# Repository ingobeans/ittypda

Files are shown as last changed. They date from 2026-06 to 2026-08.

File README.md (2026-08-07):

# ittyPDA
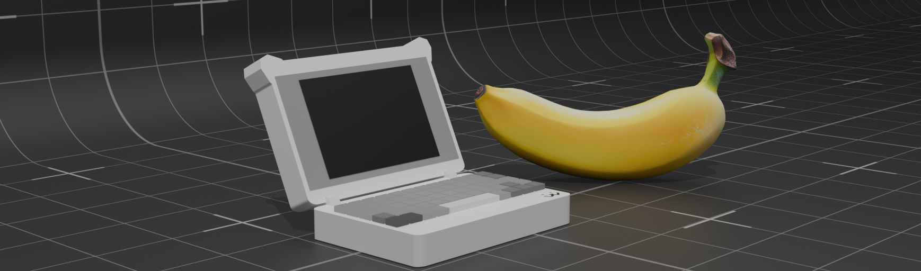
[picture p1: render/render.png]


hi! this is my little thing im working on.

ittyPDA is an itty-bitty PDA/cyberdeck thingy. its smaller than a nintendo ds but has a real keyboard and a full color IPS LCD display, powered by an STM32 microcontroller.

it's mainly intended for note-taking/writing, playing silly little videogames, and just being a very hackable little computer.

this repo contains both the hardware designs, under the `ittypda/` subdirectory, as well as the operating system under `ittyOS/`. 3D case files are under `case/`.

## specs & parts

* microprocessor: [STM32F411RET6](https://www.st.com/en/microcontrollers-microprocessors/stm32f411re.html)
    * Up to 100 MHz
    * 512 Kb flash
    * 128 Kb RAM
* display: [3.5" IPS display (no touch version)](https://www.lcdwiki.com/3.5inch_IPS_SPI_Module_ST7796)
* storage: SD card slot included on display
* charging/data transfer possible over USB-C
* battery: 2200mAh LiPo - [this is the one I use, but really any battery with a similar size and connector will work](https://www.amazon.se/-/en/gp/product/B0D7VT93JX?smid=A2YUU8D7JQVZCY&th=1)
* on-board charging circuitry powered by a [BQ24040DSQR](https://www.ti.com/product/BQ24040)
    * also battery level sensing

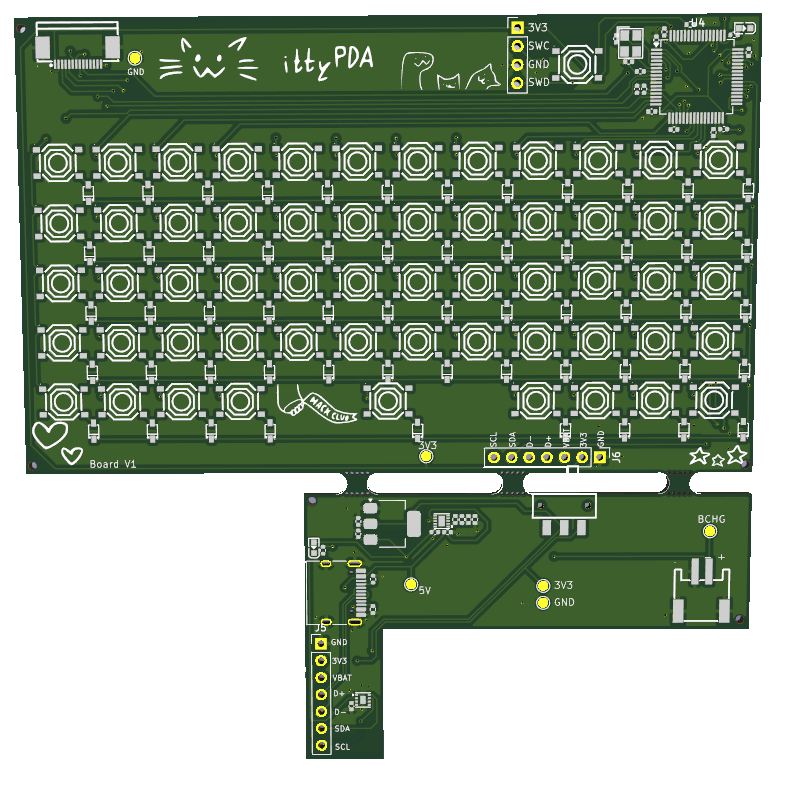
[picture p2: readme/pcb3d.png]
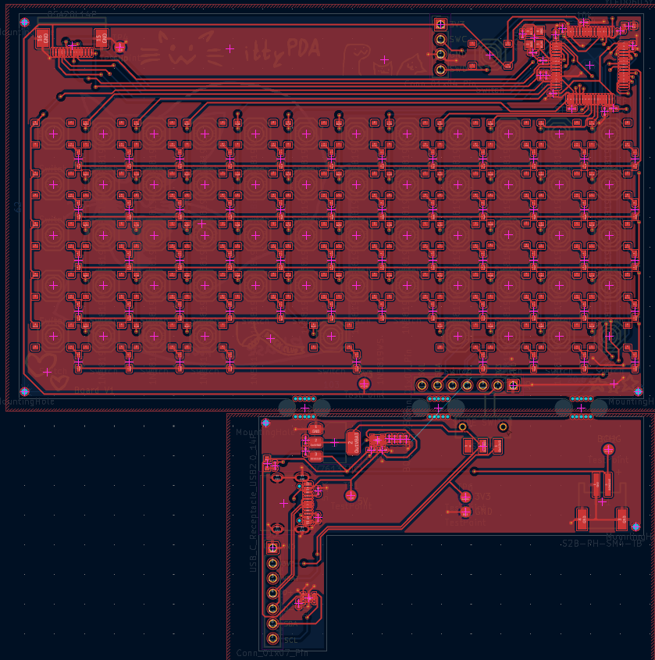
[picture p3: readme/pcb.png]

## download symbols/footprints

to open the kicad project, youll need to download some footprints. my parts are sourced from JLCPCB's parts / LCSC, and you can use [`easyeda2kicad`](https://github.com/uPesy/easyeda2kicad.py) to download LCSC parts to kicad.

the command you need to run is: 

```bash
easyeda2kicad --full --lcsc_id C318884 C191023 C22435642 C13738 C81080 C49023767 C19273152 C165948 C295747 C20416998 C2682616
```

which will download footprints/symbols/3d models for the switches, diodes, etc.

## project status (important !!)

project is in a very early WIP state currently! the PCB is the only truly *finished* part so far.

the case is just a minimum-viable-product for now, and the firmware mostly acts as a proof-of-concept regarding graphics streaming and input handling from the keyboard matrix.

thus the project is mostly about the creation of the PCB, with the case and firmware mostly just acting as beta features used to test the PCB itself.

these features will be developed in the coming months though, and when i have guaranteed that the core PCB does work! this is a project i intend to gradually work on for a long time !

## schematic / PCB

the schematic and PCB are designed in KiCad, files for which are found in `ittypda/`.

the PCB is split in two seperate parts. this is done to achieve a budget 4-layer board, and to get around the fact that JLCPCB's economy PCBA service cant assemble parts on the bottomside of the board.

the mainboard houses the microcontroller, the keypad, and display connector.

the secondary board houses the usb-c port, battery charging ic, voltage regulator, etc.

the two boards mount together like a PCB-sandwich and connect through 7 soldered pads.

showcase how the two boards are mounted:

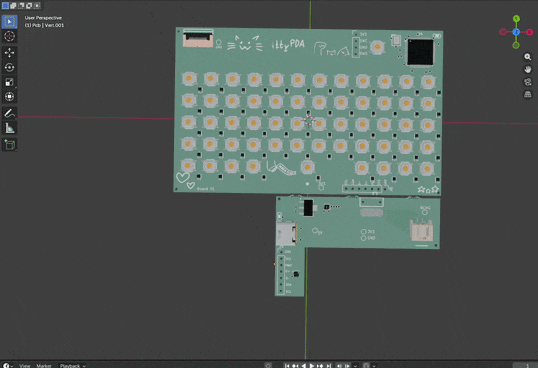
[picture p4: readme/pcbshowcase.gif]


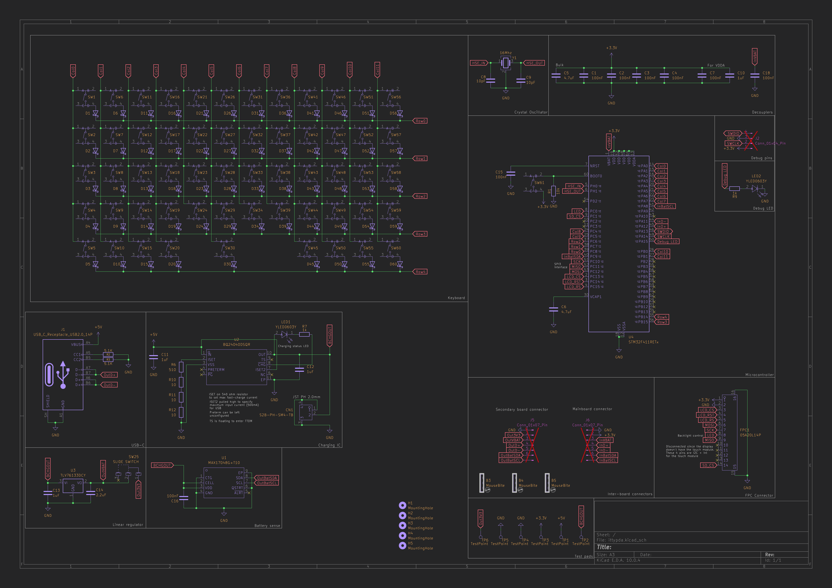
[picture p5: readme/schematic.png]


## firmware - ittyOS

ittyOS is currently in an early proof of concept state, but will have many different apps later on.

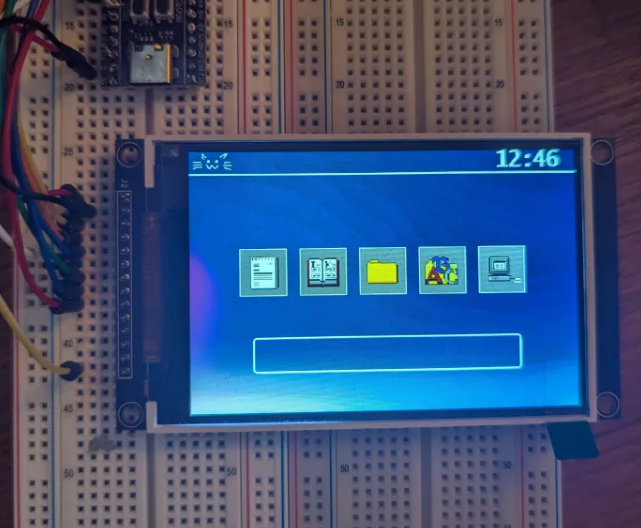
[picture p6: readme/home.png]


implemented:
* display drivers
* reading from microSD card
* streaming image data from microSD to screen
* input from keyboard
* program switching
* basic home screen
* basic notes app

todo:
* improve text input
* usb file transfer
* more apps!
    * wordle
    * journal
* different themes?

### compile ittyOS

the `../firmware` folder contains the low level hardware setup for different boards that can run ittyOS, while `ittyOS/` contains the shared code and the actual system, which is then linked to from the firmware.

you'll need to generate the firmware code from the STM32 project file, since the low-level drivers for these boards are very large and therefore gitignored. you'll need STM32CubeMX. then just open the project file for the firmware you want to build, and hit generate code. 

you'll also have to tell your LSP which CMakeLists you're using.

then, to build, navigate to the firmware you want to build's directory.

1. `cmake --preset Debug` (you only have to run this once)
2. `cmake --build --preset Debug`
3. `STM32_Programmer_CLI -c port=swd -w build/Debug/<DEVBOARD OR ITTYPDA HERE>.elf -v -rst`

## case

the case files are located under `case/`.

the case is designed in,.. blender. its mostly a MVP for a case, and when i get the phyiscal PCB, this and the firmware will be the major focus for the project moving forwards.

most parts are designed to friction-fit, though i wont know how well this works in practice, but will find out soon !

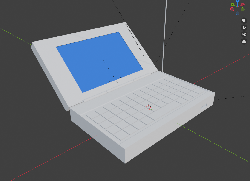
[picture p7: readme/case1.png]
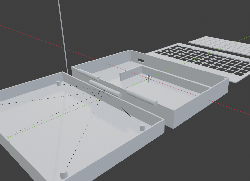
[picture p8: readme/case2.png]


## BOMs

### Final bom (bom.csv)

|Name |Cost ($) |Source |
|---|---|---|
|PCB |13.43 |JLCPCB |
|PCB Assembly Fees |48.21 |JLCPCB |
|PCB Assembly Components |20.55 |JLCPCB |
|PCB Shipping |24.07 | DHL Express |
|Customs & taxes | 26.56 | |
|Total |132.77 | |

### Parts bom (parts-bom.csv)

|Part Name |Description |Link |Quantity |Total Price ($) |
|---|---|---|---|---|
|CL05B104KO5NNNC |100nF 0402 Ceramic Capacitors |https://jlcpcb.com/partdetail/1877-CL05B104KO5NNNC/C1525 |16 |0.0864 |
|CL05A475MP5NRNC |10V 0402 Ceramic Capacitors |https://jlcpcb.com/partdetail/24469-CL05A475MP5NRNC/C23733 |4 |0.0828 |
|CL05C100JB5NNNC |10pF 0402 Ceramic Capacitors |https://jlcpcb.com/partdetail/33914-CL05C100JB5NNNC/C32949 |4 |0.0212 |
|CL05A105KA5NQNC |1uF 0402 Ceramic Capacitors |https://jlcpcb.com/partdetail/53938-CL05A105KA5NQNC/C52923 |8 |0.1272 |
|CL05A225MQ5NSNC |2.2uF 0402 Ceramic Capacitors |https://jlcpcb.com/partdetail/13164-CL05A225MQ5NSNC/C12530 |2 |0.0128 |
|S2B-PH-SM4-TB(LF)(SN) |PH JST Connector 2mm |https://jlcpcb.com/partdetail/JST-S2B_PH_SM4_TB_LF_SN/C295747 |2 |0.427 |
|1N5819WS |Schottky Diodes |https://jlcpcb.com/partdetail/GuangdongHottech-1N5819WS/C191023 |114 |1.5504 |
|05A20L14P |FPC Connector |https://jlcpcb.com/partdetail/HanElectricity-05A20L14P/C22435642 |2 |0.1404 |
|TYPE-C-31-M-12 |USB-C Connectors |https://jlcpcb.com/partdetail/Korean_HropartsElec-TYPE_C_31_M12/C165948 |2 |0.3686 |
|YLED0603Y |Yellow 0603 LED |https://jlcpcb.com/partdetail/YONGYUTAI-YLED0603Y/C19273152 |20 |0.13 |
|0402WGF1002TCE |10k ohm 0402 Resistor |https://jlcpcb.com/partdetail/26487-0402WGF1002TCE/C25744 |2 |0.023 |
|0402WGF5101TCE |5.1k ohm 0402 Resistor |https://jlcpcb.com/partdetail/26648-0402WGF5101TCE/C25905 |4 |0.0268 |
|0402WGF5100TCE |510 ohm 0402 Resistor |https://jlcpcb.com/partdetail/25866-0402WGF5100TCE/C25123 |2 |0.0122 |
|0402WGF1001TCE |1k ohm 0402 Resistor |https://jlcpcb.com/partdetail/12256-0402WGF1001TCE/C11702 |4 |0.0392 |
|0402WGF100JTCE |10 ohm 0402 Resistor |https://jlcpcb.com/partdetail/25820-0402WGF100JTCE/C25077 |6 |0.0342 |
|TS-1187A-B-A-B |Tactile Switches |https://jlcpcb.com/partdetail/XKBConnection-TS_1187A_B_AB/C318884 |116 |2.3664 |
|MST-12D18G4 SPDT | Slide Switch |https://jlcpcb.com/partdetail/C49023767 |2 |0.1654 |
|MAX17048G+T10 |Battery Sense IC MAX17048GT10 |https://jlcpcb.com/partdetail/2777647-MAX17048GT10/C2682616 |2 |4.3212 |
|BQ24040DSQR |Lithium Battery Charge IC BQ24040DSQR |https://jlcpcb.com/partdetail/TexasInstruments-BQ24040DSQR/C81080 |5 |2.243 |
|TLV76133DCYR |3.3V Fixed Voltage Regulators - Linear|https://jlcpcb.com/partdetail/TexasInstruments-TLV76133DCYR/C7527500 |2 |0.438 |
|STM32F411RET6 |Microcontroller |https://jlcpcb.com/partdetail/STMicroelectronics-STM32F411RET6/C94355 |2 |7.7452 |
|X322516MLB4SI |16MHz 9pF Crystal Oscillator |https://jlcpcb.com/partdetail/YXC_CrystalOscillators-X322516MLB4SI/C13738 |2 |0.1856 |

<hr>

<sup>no ai usage</sup>

<sup>made with <3</sup>

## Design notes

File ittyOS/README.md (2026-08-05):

# ittyOS

hiya! this folder contains the code for the shared operating system. 

the `../firmware` folder contains the low level hardware setup for different boards that can run ittyOS, that all link to this directory and act as bootloaders.

the `FS/` directory contains the files i have on my microSD card which contains some images used by ittyOS. how this works will be changed later in development with automatic SD card formatting tools, but for now you can simply format your SD card for FAT and upload this filetree.

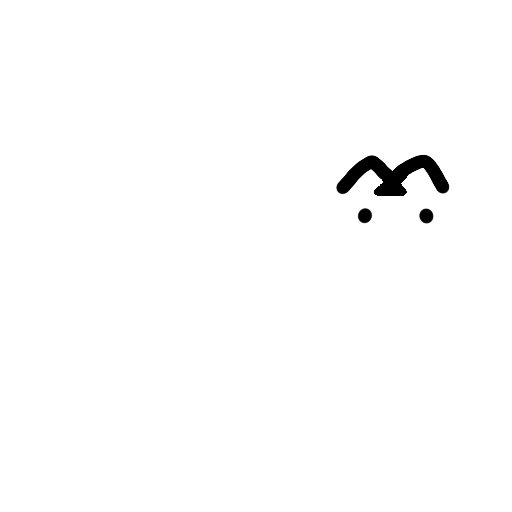
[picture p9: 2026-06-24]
render/decal.png

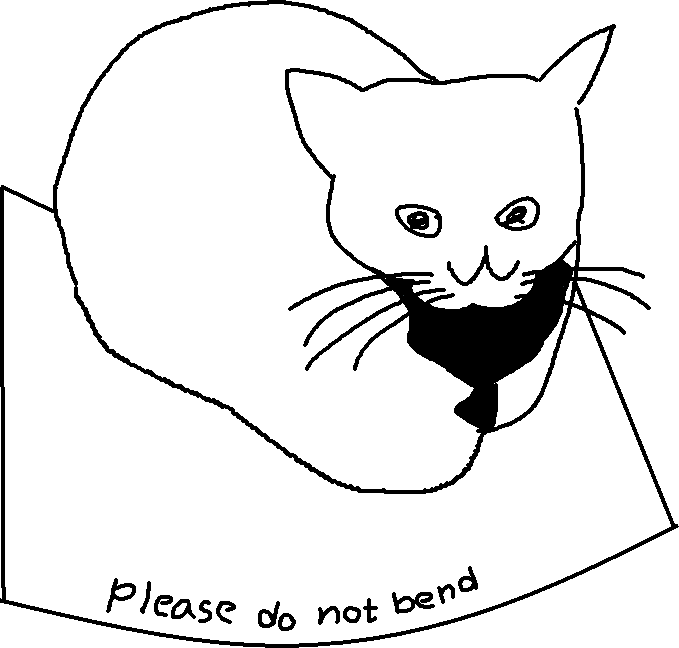
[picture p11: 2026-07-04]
ittypda/silkscreen/bend.png

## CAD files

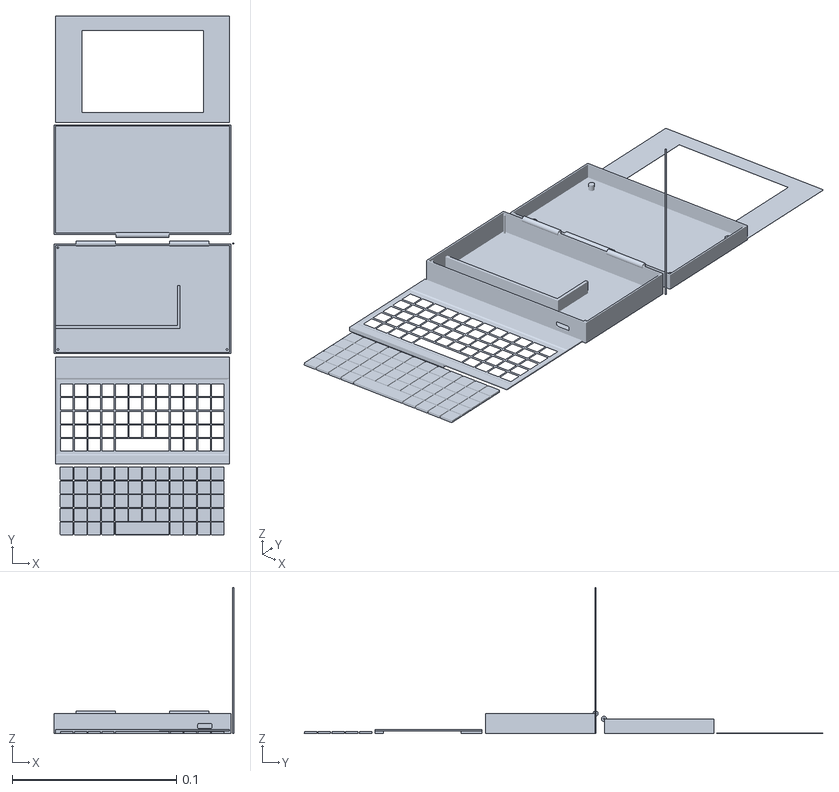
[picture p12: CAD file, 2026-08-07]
case/case-printable.stl
0.109 x 0.316 x 0.0891

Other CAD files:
case/case-printable.blend
mockup.blend

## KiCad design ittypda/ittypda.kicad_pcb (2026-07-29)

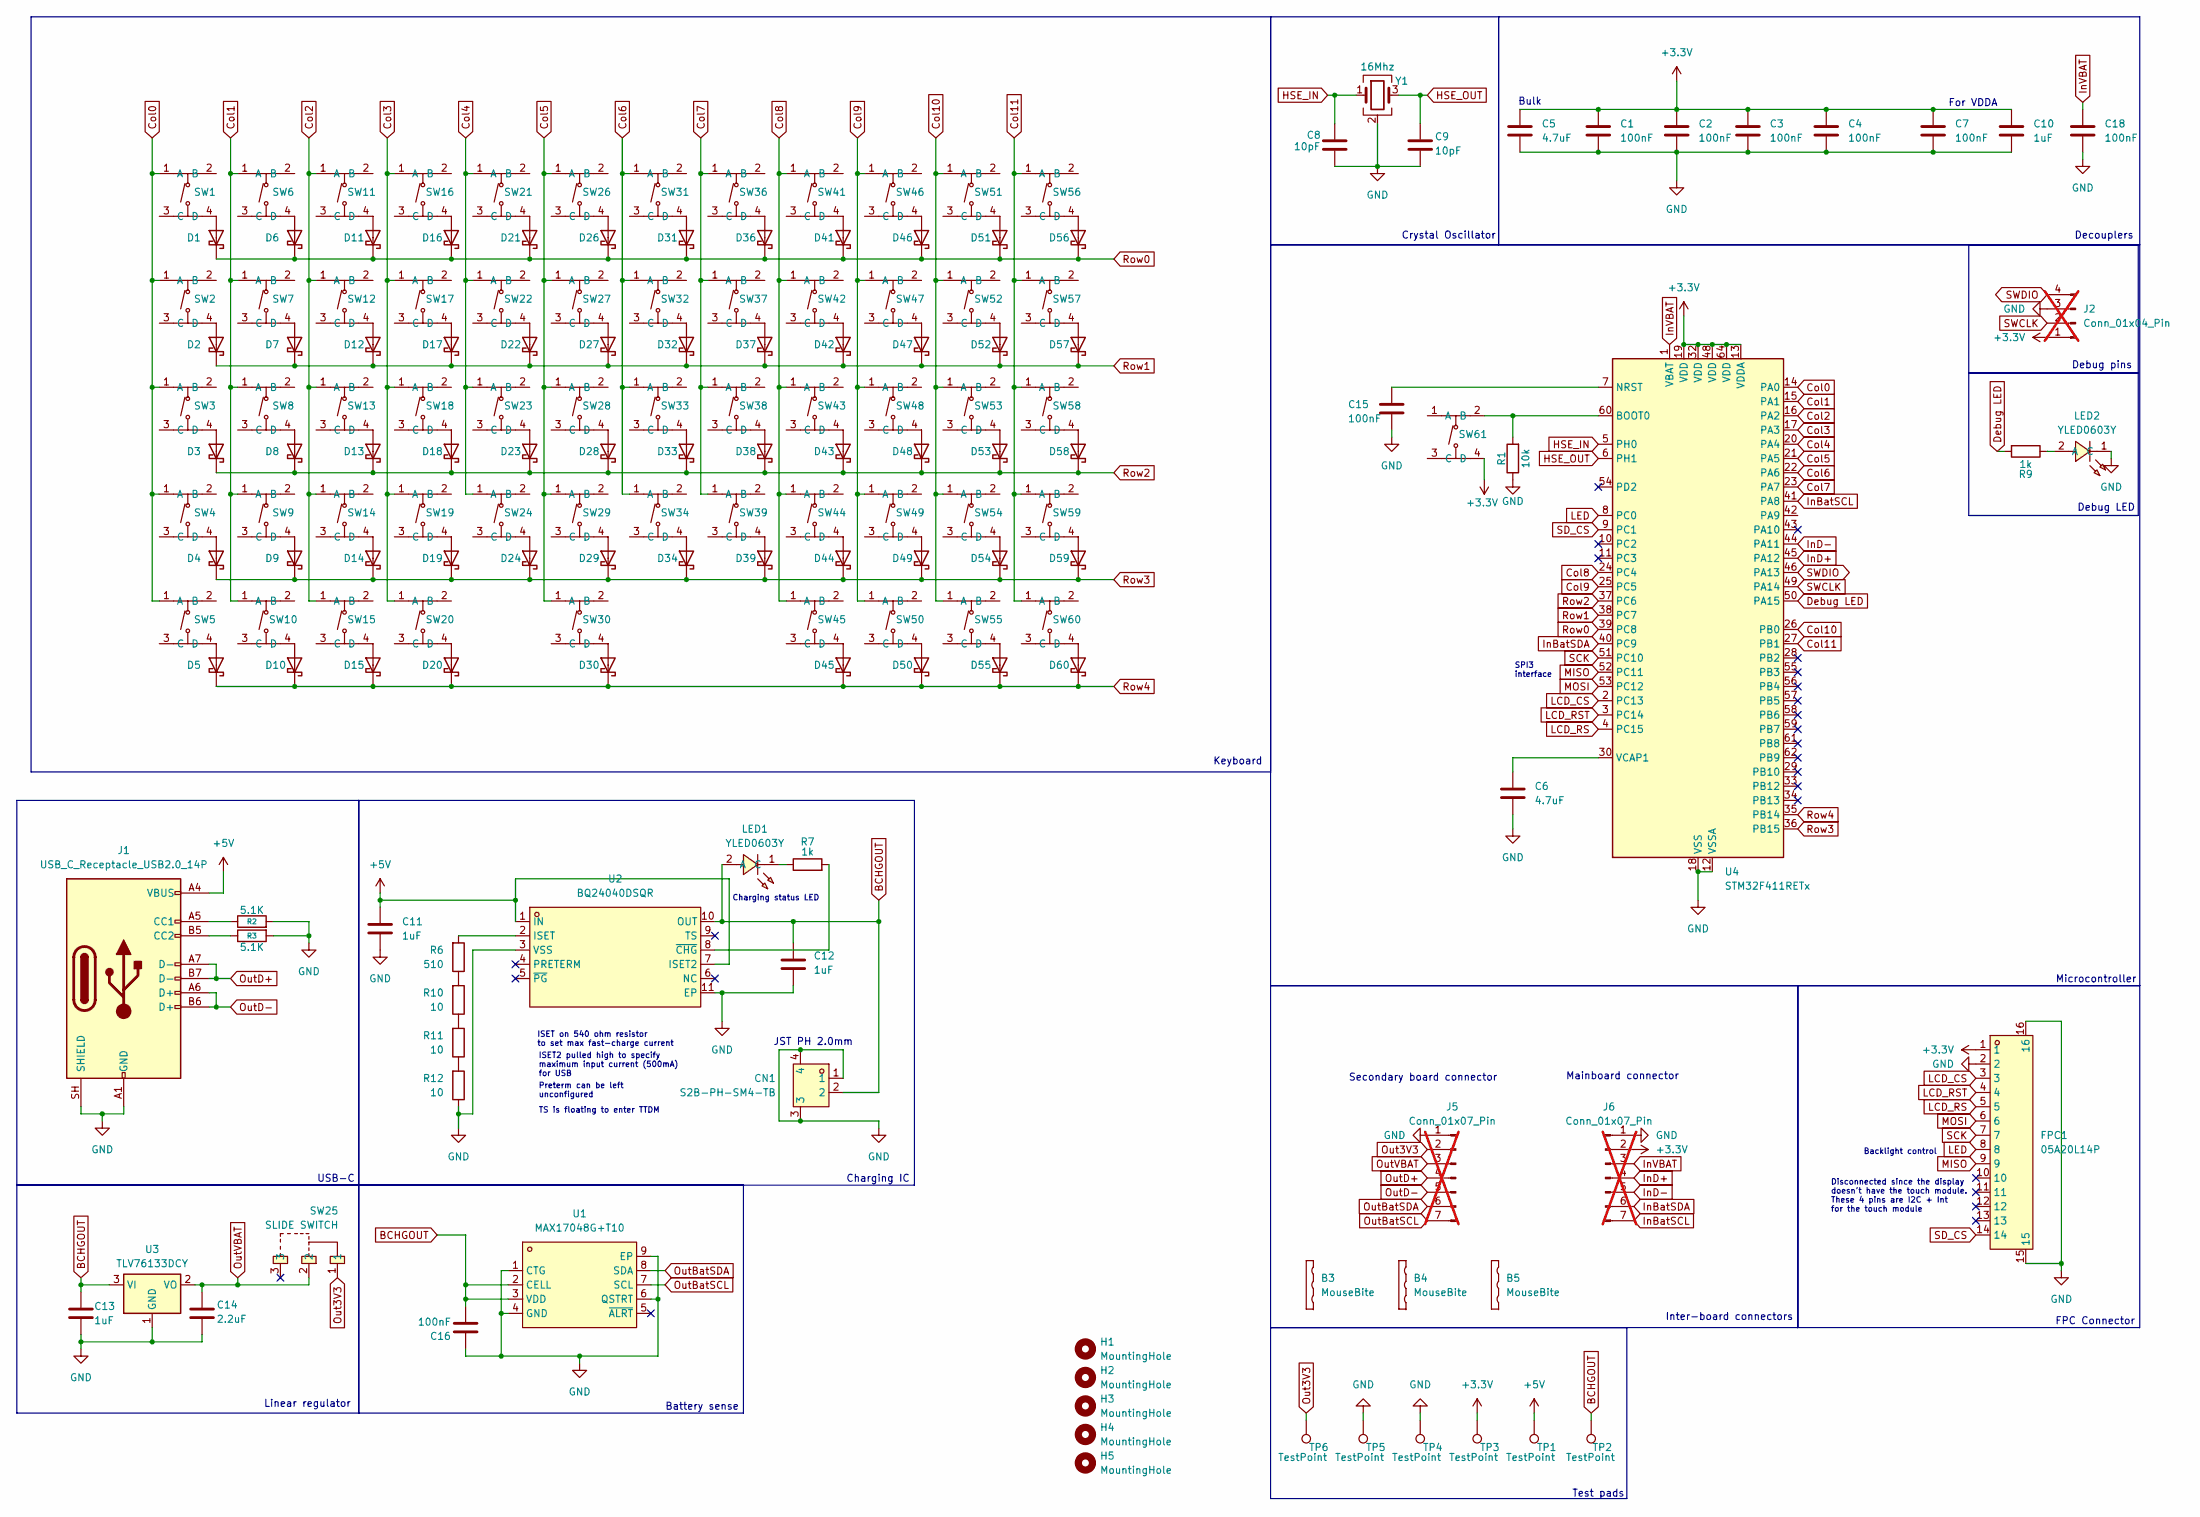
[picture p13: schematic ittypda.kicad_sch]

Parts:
B3, B4, B5: MouseBite; mouse-bite-3mm-slot
C1, C2, C3, C4, C7, C15, C16, C18: 100nF; C_0402_1005Metric
C5, C6: 4.7uF; C_0402_1005Metric
C8, C9: 10pF; C_0402_1005Metric
C10, C11, C12, C13: 1uF; C_0402_1005Metric
C14: 2.2uF; C_0402_1005Metric
CN1: S2B-PH-SM4-TB; CONN-SMD_P2.00_S2B-PH-SM4-TB-LF-SN; MPN S2B-PH-SM4-TB(LF)(SN); LCSC Part C295747
D1, D2, D3, D4, D5, D6, D7, D8, D9, D10, D11, D12, D13, D14, D15, D16, D17, D18, D19, D20, D21, D22, D23, D24, D26, D27, D28, D29, D30, D31, D32, D33, D34, D36, D37, D38, D39, D41, D42, D43, D44, D45, D46, D47, D48, D49, D50, D51, D52, D53, D54, D55, D56, D57, D58, D59, D60: 1N5819WS; SOD-323_L1.8-W1.3-LS2.5-RD; Forward Voltage (Vf@If) 600mV@1A; Reverse Voltage (Vr) 40V; Part 1N5819WS; LCSC C191023
FPC1: 05A20L14P; CONN-SMD_05A20L14P; MPN 05A20L14P; LCSC Part C22435642
H1, H2, H3, H4, H5: MountingHole; ToolingHole_1.152mm
J1: USB_C_Receptacle_USB2.0_14P; USB_C_Receptacle_HRO_TYPE-C-31-M-12; LCSC Part C165948
J2: Conn_01x04_Pin; PinHeader_1x04_P2.54mm_Vertical; not fitted
J5, J6: Conn_01x07_Pin; PinHeader_1x07_P2.54mm_Vertical; not fitted
LED1, LED2: YLED0603Y; LED0603-RD-1; MPN YLED0603Y; LCSC Part C19273152
R1: 10k; R_0402_1005Metric
R2, R3: 5.1K; R_0402_1005Metric
R6: 510; R_0402_1005Metric
R7, R9: 1k; R_0402_1005Metric
R10, R11, R12: 10; R_0402_1005Metric
SW1, SW2, SW3, SW4, SW5, SW6, SW7, SW8, SW9, SW10, SW11, SW12, SW13, SW14, SW15, SW16, SW17, SW18, SW19, SW20, SW21, SW22, SW23, SW24, SW26, SW27, SW28, SW29, SW30, SW31, SW32, SW33, SW34, SW36, SW37, SW38, SW39, SW41, SW42, SW43, SW44, SW45, SW46, SW47, SW48, SW49, SW50, SW51, SW52, SW53, SW54, SW55, SW56, SW57, SW58, SW59, SW60, SW61: Switch; SW-SMD_4P-L5.1-W5.1-P3.70-LS6.5-TL_H1.5; MPN TS-1187A-B-A-B; LCSC Part C318884
SW25: SLIDE SWITCH; SW-SMD_MST-12D18G4-SPDT-SLIDE-SWITCH; MPN MST-12D18G2 SMD Slide Switch; LCSC Part C49023767
TP1, TP2, TP3, TP4, TP5, TP6: TestPoint; TestPoint_Pad_D1.5mm
U1: MAX17048G+T10; TDFN-8_L2.0-W2.0-P0.50-BL-EP1.2; MPN MAX17048G+T10; LCSC Part C2682616
U2: BQ24040DSQR; WSON-10_L2.0-W2.0-P0.40-BL-EP; MPN BQ24040DSQR; LCSC Part C81080
U3: TLV76133DCY; SOT-223-3_TabPin2
U4: STM32F411RETx; LQFP-64_10x10mm_P0.5mm
Y1: 16Mhz; CRYSTAL-SMD_4P-L3.2-W2.5-BL

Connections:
+3.3V: C1.1, C2.1, C3.1, C4.1, C5.1, C7.1, C10.1, FPC1.1, J2.1, J6.2, SW61.4 (D), TP3.1 (1_1), U4.13 (VDDA), U4.19 (VDD), U4.32 (VDD), U4.48 (VDD), U4.64 (VDD)
+5V: C11.1, J1.A4 (VBUS), J1.A9 (VBUS), J1.B4 (VBUS), J1.B9 (VBUS), TP1.1 (1_1), U2.1 (IN), U2.7 (ISET2)
BCHGOUT: C12.1, C13.1, C16.2, CN1.2, LED1.2 (A), TP2.1 (1_1), U1.2 (CELL), U1.3 (VDD), U2.10 (OUT), U3.3 (VI)
Col0: SW1.1 (A), SW2.1 (A), SW3.1 (A), SW4.1 (A), SW5.1 (A), U4.14 (PA0)
Col1: SW6.1 (A), SW7.1 (A), SW8.1 (A), SW9.1 (A), SW10.1 (A), U4.15 (PA1)
Col2: SW11.1 (A), SW12.1 (A), SW13.1 (A), SW14.1 (A), SW15.1 (A), U4.16 (PA2)
Col3: SW16.1 (A), SW17.1 (A), SW18.1 (A), SW19.1 (A), SW20.1 (A), U4.17 (PA3)
Col4: SW21.1 (A), SW22.1 (A), SW23.1 (A), SW24.1 (A), U4.20 (PA4)
Col5: SW26.1 (A), SW27.1 (A), SW28.1 (A), SW29.1 (A), SW30.1 (A), U4.21 (PA5)
Col6: SW31.1 (A), SW32.1 (A), SW33.1 (A), SW34.1 (A), U4.22 (PA6)
Col7: SW36.1 (A), SW37.1 (A), SW38.1 (A), SW39.1 (A), U4.23 (PA7)
Col8: SW41.1 (A), SW42.1 (A), SW43.1 (A), SW44.1 (A), SW45.1 (A), U4.24 (PC4)
Col9: SW46.1 (A), SW47.1 (A), SW48.1 (A), SW49.1 (A), SW50.1 (A), U4.25 (PC5)
Col10: SW51.1 (A), SW52.1 (A), SW53.1 (A), SW54.1 (A), SW55.1 (A), U4.26 (PB0)
Col11: SW56.1 (A), SW57.1 (A), SW58.1 (A), SW59.1 (A), SW60.1 (A), U4.27 (PB1)
Debug LED: R9.2, U4.50 (PA15)
GND: C1.2, C2.2, C3.2, C4.2, C5.2, C6.2, C7.2, C8.2, C9.2, C10.2, C11.2, C12.2, C13.2, C14.2, C15.2, C16.1, C18.2, CN1.1, CN1.3, CN1.4, FPC1.2, FPC1.15, FPC1.16, J1.A1 (GND), J1.A12 (GND), J1.B1 (GND), J1.B12 (GND), J1.SH (SHIELD), J2.3, J5.1, J6.1, LED2.1 (C), R1.1, R2.2, R3.2, R12.1, TP4.1 (1_1), TP5.1 (1_1), U1.1 (CTG), U1.4 (GND), U1.6 (QSTRT), U1.9 (EP), U2.3 (VSS), U2.11 (EP), U3.1 (GND), U4.12 (VSSA), U4.18 (VSS), U4.31 (VSS), U4.47 (VSS), U4.63 (VSS), Y1.2 (G), Y1.4 (G)
HSE_IN: C8.1, U4.5 (PH0), Y1.1
HSE_OUT: C9.1, U4.6 (PH1), Y1.3
InBatSCL: J6.7, U4.41 (PA8)
InBatSDA: J6.6, U4.40 (PC9)
InD+: J6.4, U4.45 (PA12)
InD-: J6.5, U4.44 (PA11)
InVBAT: C18.1, J6.3, U4.1 (VBAT)
LCD_CS: FPC1.3, U4.2 (PC13)
LCD_RS: FPC1.5, U4.4 (PC15)
LCD_RST: FPC1.4, U4.3 (PC14)
LED: FPC1.8, U4.8 (PC0)
MISO: FPC1.9, U4.52 (PC11)
MOSI: FPC1.6, U4.53 (PC12)
unnamed: J1.A5 (CC1), R2.1
unnamed: J1.B5 (CC2), R3.1
unnamed: LED1.1 (C), R7.1
unnamed: LED2.2 (A), R9.1
unnamed: R10.1, R11.2
unnamed: R6.1, R10.2
unnamed: R11.1, R12.2
unnamed: D1.2, SW1.4 (D)
unnamed: D2.2, SW2.4 (D)
unnamed: D3.2, SW3.4 (D)
unnamed: D4.2, SW4.4 (D)
unnamed: D5.2, SW5.4 (D)
unnamed: D6.2, SW6.4 (D)
unnamed: D7.2, SW7.4 (D)
unnamed: D8.2, SW8.4 (D)
unnamed: D9.2, SW9.4 (D)
unnamed: D10.2, SW10.4 (D)
unnamed: D11.2, SW11.4 (D)
unnamed: D12.2, SW12.4 (D)
unnamed: D13.2, SW13.4 (D)
unnamed: D14.2, SW14.4 (D)
unnamed: D15.2, SW15.4 (D)
unnamed: D16.2, SW16.4 (D)
unnamed: D17.2, SW17.4 (D)
unnamed: D18.2, SW18.4 (D)
unnamed: D19.2, SW19.4 (D)
unnamed: D20.2, SW20.4 (D)
unnamed: D21.2, SW21.4 (D)
unnamed: D22.2, SW22.4 (D)
unnamed: D23.2, SW23.4 (D)
unnamed: D24.2, SW24.4 (D)
unnamed: D26.2, SW26.4 (D)
unnamed: D27.2, SW27.4 (D)
unnamed: D28.2, SW28.4 (D)
unnamed: D29.2, SW29.4 (D)
unnamed: D30.2, SW30.4 (D)
unnamed: D31.2, SW31.4 (D)
unnamed: D32.2, SW32.4 (D)
unnamed: D33.2, SW33.4 (D)
unnamed: D34.2, SW34.4 (D)
unnamed: D36.2, SW36.4 (D)
unnamed: D37.2, SW37.4 (D)
unnamed: D38.2, SW38.4 (D)
unnamed: D39.2, SW39.4 (D)
unnamed: D41.2, SW41.4 (D)
unnamed: D42.2, SW42.4 (D)
unnamed: D43.2, SW43.4 (D)
unnamed: D44.2, SW44.4 (D)
unnamed: D45.2, SW45.4 (D)
unnamed: D46.2, SW46.4 (D)
unnamed: D47.2, SW47.4 (D)
unnamed: D48.2, SW48.4 (D)
unnamed: D49.2, SW49.4 (D)
unnamed: D50.2, SW50.4 (D)
unnamed: D51.2, SW51.4 (D)
unnamed: D52.2, SW52.4 (D)
unnamed: D53.2, SW53.4 (D)
unnamed: D54.2, SW54.4 (D)
unnamed: D55.2, SW55.4 (D)
unnamed: D56.2, SW56.4 (D)
unnamed: D57.2, SW57.4 (D)
unnamed: D58.2, SW58.4 (D)
unnamed: D59.2, SW59.4 (D)
unnamed: D60.2, SW60.4 (D)
unnamed: R1.2, SW61.2 (B), U4.60 (BOOT0)
unnamed: R6.2, U2.2 (ISET)
unnamed: R7.2, U2.8 (~CHG)
unnamed: C15.1, U4.7 (NRST)
unnamed: C6.1, U4.30 (VCAP1)
Out3V3: J5.2, SW25.1, TP6.1 (1_1)
OutBatSCL: J5.7, U1.7 (SCL)
OutBatSDA: J5.6, U1.8 (SDA)
OutD+: J1.A7 (D-), J1.B7 (D-), J5.4
OutD-: J1.A6 (D+), J1.B6 (D+), J5.5
OutVBAT: C14.1, J5.3, SW25.2, U3.2 (VO)
Row0: D1.1, D6.1, D11.1, D16.1, D21.1, D26.1, D31.1, D36.1, D41.1, D46.1, D51.1, D56.1, U4.39 (PC8)
Row1: D2.1, D7.1, D12.1, D17.1, D22.1, D27.1, D32.1, D37.1, D42.1, D47.1, D52.1, D57.1, U4.38 (PC7)
Row2: D3.1, D8.1, D13.1, D18.1, D23.1, D28.1, D33.1, D38.1, D43.1, D48.1, D53.1, D58.1, U4.37 (PC6)
Row3: D4.1, D9.1, D14.1, D19.1, D24.1, D29.1, D34.1, D39.1, D44.1, D49.1, D54.1, D59.1, U4.36 (PB15)
Row4: D5.1, D10.1, D15.1, D20.1, D30.1, D45.1, D50.1, D55.1, D60.1, U4.35 (PB14)
SCK: FPC1.7, U4.51 (PC10)
SD_CS: FPC1.14, U4.9 (PC1)
SWCLK: J2.2, U4.49 (PA14)
SWDIO: J2.4, U4.46 (PA13)

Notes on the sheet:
For VDDA
Backlight control
ISET on 540 ohm resistor to set max fast-charge current
Disconnected since the display doesn't have the touch module. These 4 pins are I2C + Int for the touch module
Preterm can be left unconfigured
TS is floating to enter TTDM
Secondary board connector
Microcontroller
SPI3 interface
Keyboard
Battery sense
Debug LED
JST PH 2.0mm
USB-C
Test pads
Inter-board connectors
Debug pins
Crystal Oscillator
Linear regulator
Charging IC
Mainboard connector
Decouplers
FPC Connector
ISET2 pulled high to specify maximum input current (500mA) for USB
Charging status LED
Bulk

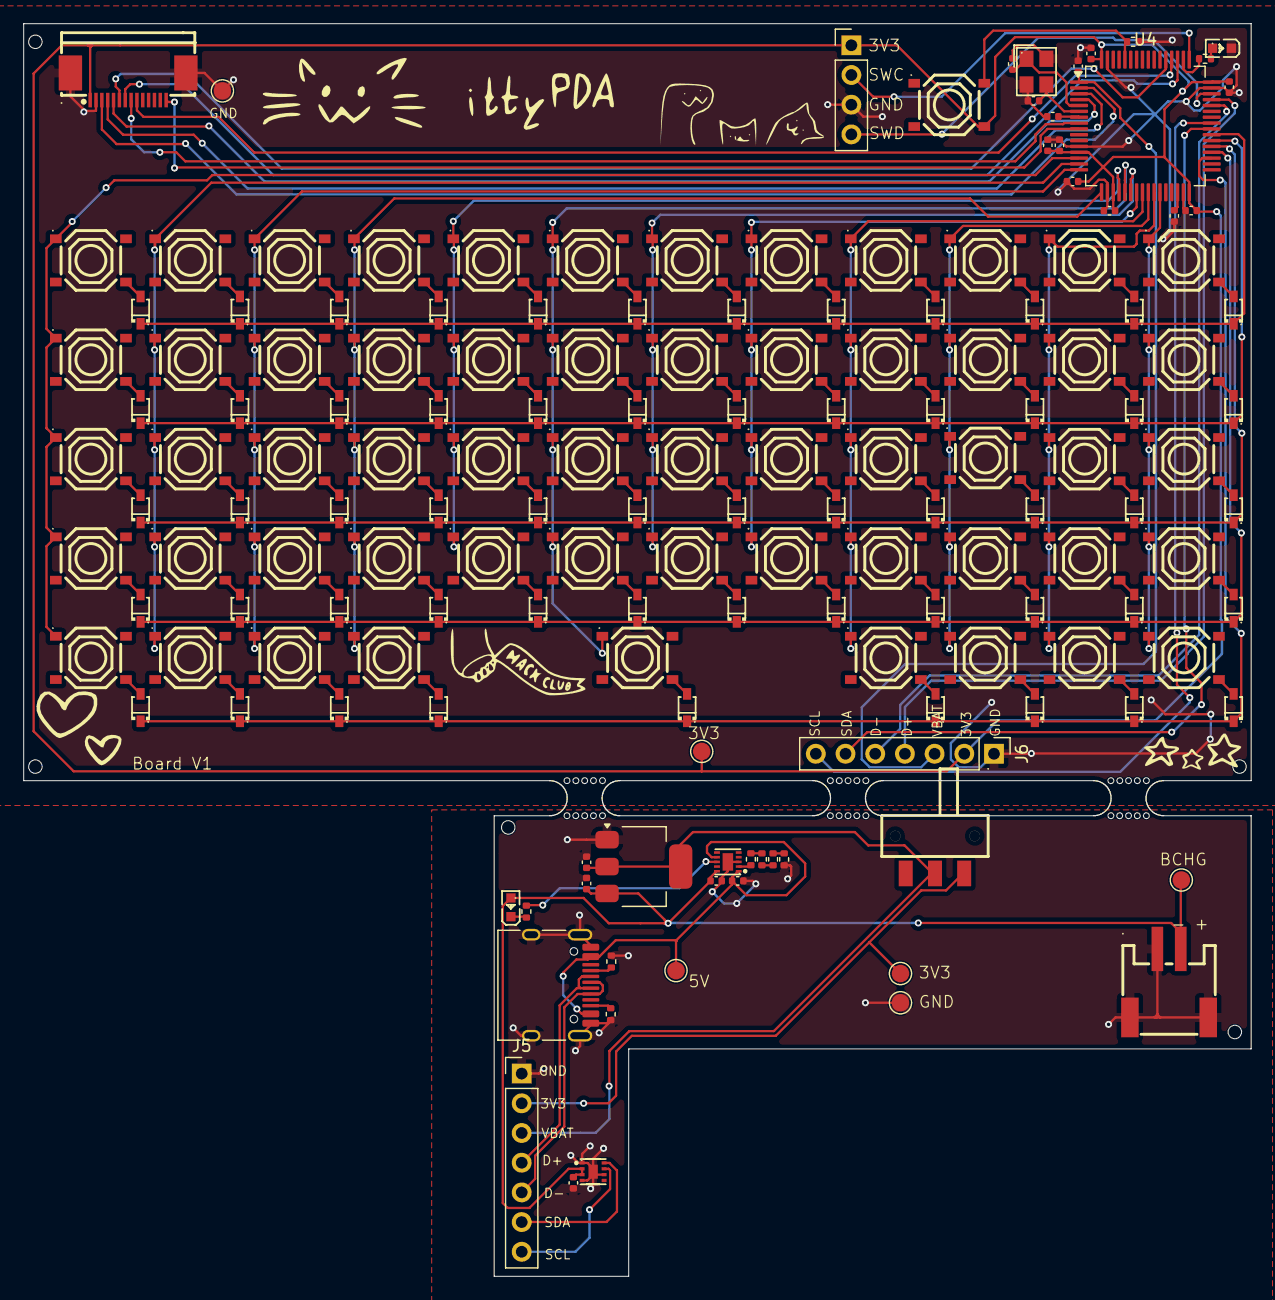
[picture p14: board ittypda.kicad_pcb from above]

Board: 2 copper layers, 105.0 x 107.2 mm, 169 parts (0 on the bottom side), 114 nets.

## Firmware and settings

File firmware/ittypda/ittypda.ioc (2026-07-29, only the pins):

Mcu.UserName=STM32F411RETx
PA0-WKUP.Signal=GPIO_Output
PA1.Signal=GPIO_Output
PA11.Signal=USB_OTG_FS_DM
PA12.Signal=USB_OTG_FS_DP
PA13.Signal=SYS_JTMS-SWDIO
PA14.Signal=SYS_JTCK-SWCLK
PA2.Signal=GPIO_Output
PA3.Signal=GPIO_Output
PA4.Signal=GPIO_Output
PA5.Signal=GPIO_Output
PA6.Signal=GPIO_Output
PA7.Signal=GPIO_Output
PA8.Signal=I2C3_SCL
PB0.Signal=GPIO_Output
PB1.Signal=GPIO_Output
PB14.Signal=GPIO_Input
PB15.Signal=GPIO_Input
PC0.Signal=GPIO_Output
PC1.Signal=GPIO_Output
PC10.Signal=SPI3_SCK
PC11.Signal=SPI3_MISO
PC12.Signal=SPI3_MOSI
PC13-ANTI_TAMP.Signal=GPIO_Output
PC14-OSC32_IN.Signal=GPIO_Output
PC15-OSC32_OUT.Signal=GPIO_Output
PC4.Signal=GPIO_Output
PC5.Signal=GPIO_Output
PC6.Signal=GPIO_Input
PC7.Signal=GPIO_Input
PC8.Signal=GPIO_Input
PC9.Signal=I2C3_SDA

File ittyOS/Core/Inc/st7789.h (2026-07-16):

#ifndef __ST7789_H
#define __ST7789_H

#include "fonts.h"
#include "system.h"

/* choose a Hardware SPI port to use. */
#define ST7789_SPI_PORT HSPI
extern SPI_HandleTypeDef ST7789_SPI_PORT;

/* choose whether use DMA or not */
#define USE_DMA

/* If u need CS control, comment below*/
// #define CFG_NO_CS

/* Pin connection*/

// #define MOSI GPIO_PIN_12 // C
// #define MISO GPIO_PIN_11 // C
// #define SCK GPIO_PIN_12 // B

// lib defs
#define ST7789_RST_PORT LCD_RST_PORT
#define ST7789_RST_PIN LCD_RST
#define ST7789_DC_PORT LCD_RS_PORT
#define ST7789_DC_PIN LCD_RS

#ifndef CFG_NO_CS
#define ST7789_CS_PORT LCD_CS_PORT
#define ST7789_CS_PIN LCD_CS
#endif

// my display

#define ST7789_ROTATION 3

#define USING_480X320
// #define USING_135X240
// #define USING_240X240
// #define USING_170X320
#ifdef USING_480X320
#define ST7789_WIDTH 480
#define ST7789_HEIGHT 320
#if ST7789_ROTATION == 0
#define X_SHIFT 0
#define Y_SHIFT 0
#elif ST7789_ROTATION == 1
#define X_SHIFT 0
#define Y_SHIFT 0
#elif ST7789_ROTATION == 2
#define X_SHIFT 0
#define Y_SHIFT 0
#elif ST7789_ROTATION == 3
#define X_SHIFT 0
#define Y_SHIFT 0
#endif
#endif

/* If u need Backlight control, uncomment below */
// #define BLK_PORT
// #define BLK_PIN

/*
 * Comment one to use another.
 * 3 parameters can be choosed
 * 135x240(0.96 inch) & 240x240(1.3inch) & 170x320(1.9inch)
 * X_SHIFT & Y_SHIFT are used to adapt different display's resolution
 */

/* Choose a type you are using */
// #define USING_135X240
// #define USING_240X240
// #define USING_170X320

/* Choose a display rotation you want to use: (0-3) */
// #define ST7789_ROTATION 0
// #define ST7789_ROTATION 1
// #define ST7789_ROTATION 3

#ifdef USING_135X240

#if ST7789_ROTATION == 0
#define ST7789_WIDTH 135
#define ST7789_HEIGHT 240
#define X_SHIFT 53
#define Y_SHIFT 40
#endif

#if ST7789_ROTATION == 1
#define ST7789_WIDTH 240
#define ST7789_HEIGHT 135
#define X_SHIFT 40
#define Y_SHIFT 52
#endif

#if ST7789_ROTATION == 2
#define ST7789_WIDTH 135
#define ST7789_HEIGHT 240
#define X_SHIFT 52
#define Y_SHIFT 40
#endif

#if ST7789_ROTATION == 3
#define ST7789_WIDTH 240
#define ST7789_HEIGHT 135
#define X_SHIFT 40
#define Y_SHIFT 53
#endif

#endif

#ifdef USING_240X240

#define ST7789_WIDTH 240
#define ST7789_HEIGHT 240

#if ST7789_ROTATION == 0
#define X_SHIFT 0
#define Y_SHIFT 80
#elif ST7789_ROTATION == 1
#define X_SHIFT 80
#define Y_SHIFT 0
#elif ST7789_ROTATION == 2
#define X_SHIFT 0
#define Y_SHIFT 0
#elif ST7789_ROTATION == 3
#define X_SHIFT 0
#define Y_SHIFT 0
#endif

#endif

#ifdef USING_170X320

#if ST7789_ROTATION == 0
#define ST7789_WIDTH 170
#define ST7789_HEIGHT 320
#define X_SHIFT 35
#define Y_SHIFT 0
#endif

#if ST7789_ROTATION == 1
#define ST7789_WIDTH 320
#define ST7789_HEIGHT 170
#define X_SHIFT 0
#define Y_SHIFT 35
#endif

#if ST7789_ROTATION == 2
#define ST7789_WIDTH 170
#define ST7789_HEIGHT 320
#define X_SHIFT 35
#define Y_SHIFT 0
#endif

#if ST7789_ROTATION == 3
#define ST7789_WIDTH 320
#define ST7789_HEIGHT 170
#define X_SHIFT 0
#define Y_SHIFT 35
#endif

#endif

/**
 *Color of pen
 *If you want to use another color, you can choose one in RGB565 format.
 */

#define WHITE 0xFFFF
#define BLACK 0x0000
#define BLUE 0x001F
#define RED 0xF800
#define MAGENTA 0xF81F
#define GREEN 0x07E0
#define CYAN 0x7FFF
#define YELLOW 0xFFE0
#define GRAY 0X8430
#define BRED 0XF81F
#define GRED 0XFFE0
#define GBLUE 0X07FF
#define BROWN 0XBC40
#define BRRED 0XFC07
#define DARKBLUE 0X01CF
#define LIGHTBLUE 0X7D7C
#define GRAYBLUE 0X5458

#define LIGHTGREEN 0X841F
#define LGRAY 0XC618
#define LGRAYBLUE 0XA651
#define LBBLUE 0X2B12

/* Control Registers and constant codes */
#define ST7789_NOP 0x00
#define ST7789_SWRESET 0x01
#define ST7789_RDDID 0x04
#define ST7789_RDDST 0x09

#define ST7789_SLPIN 0x10
#define ST7789_SLPOUT 0x11
#define ST7789_PTLON 0x12
#define ST7789_NORON 0x13

#define ST7789_INVOFF 0x20
#define ST7789_INVON 0x21
#define ST7789_DISPOFF 0x28
#define ST7789_DISPON 0x29
#define ST7789_CASET 0x2A
#define ST7789_RASET 0x2B
#define ST7789_RAMWR 0x2C
#define ST7789_RAMRD 0x2E

#define ST7789_PTLAR 0x30
#define ST7789_COLMOD 0x3A
#define ST7789_MADCTL 0x36

/**
 * Memory Data Access Control Register (0x36H)
 * MAP:     D7  D6  D5  D4  D3  D2  D1  D0
 * param:   MY  MX  MV  ML  RGB MH  -   -
 *
 */

/* Page Address Order ('0': Top to Bottom, '1': the opposite) */
#define ST7789_MADCTL_MY 0x80
/* Column Address Order ('0': Left to Right, '1': the opposite) */
#define ST7789_MADCTL_MX 0x40
/* Page/Column Order ('0' = Normal Mode, '1' = Reverse Mode) */
#define ST7789_MADCTL_MV 0x20
/* Line Address Order ('0' = LCD Refresh Top to Bottom, '1' = the opposite) */
#define ST7789_MADCTL_ML 0x10
/* RGB/BGR Order ('0' = RGB, '1' = BGR) */
#define ST7789_MADCTL_RGB 0x8
#define ST7789_MADCTL_MH 0x4

#define ST7789_RDID1 0xDA
#define ST7789_RDID2 0xDB
#define ST7789_RDID3 0xDC
#define ST7789_RDID4 0xDD

/* Advanced options */
#define ST7789_COLOR_MODE_16bit 0x55 //  RGB565 (16bit)
#define ST7789_COLOR_MODE_18bit 0x66 //  RGB666 (18bit)

/* Basic operations */
#define ST7789_RST_Clr()                                                       \
  HAL_GPIO_WritePin(ST7789_RST_PORT, ST7789_RST_PIN, GPIO_PIN_RESET)
#define ST7789_RST_Set()                                                       \
  HAL_GPIO_WritePin(ST7789_RST_PORT, ST7789_RST_PIN, GPIO_PIN_SET)

#define ST7789_DC_Clr()                                                        \
  HAL_GPIO_WritePin(ST7789_DC_PORT, ST7789_DC_PIN, GPIO_PIN_RESET)
#define ST7789_DC_Set()                                                        \
  HAL_GPIO_WritePin(ST7789_DC_PORT, ST7789_DC_PIN, GPIO_PIN_SET)
#ifndef CFG_NO_CS
#define ST7789_Select()                                                        \
  HAL_GPIO_WritePin(ST7789_CS_PORT, ST7789_CS_PIN, GPIO_PIN_RESET)
#define ST7789_UnSelect()                                                      \
  HAL_GPIO_WritePin(ST7789_CS_PORT, ST7789_CS_PIN, GPIO_PIN_SET)
#else
#define ST7789_Select() asm("nop")
#define ST7789_UnSelect() asm("nop")
#endif

#define ABS(x) ((x) > 0 ? (x) : -(x))

/* Basic functions. */
void ST7789_Init(void);
void ST7789_SetRotation(uint8_t m);
void ST7789_Fill_Color(uint16_t color);
void ST7789_DrawPixel(uint16_t x, uint16_t y, uint16_t color);
void ST7789_Fill(uint16_t xSta, uint16_t ySta, uint16_t xEnd, uint16_t yEnd,
                 uint16_t color);
void ST7789_DrawPixel_4px(uint16_t x, uint16_t y, uint16_t color);

/* Graphical functions. */
void ST7789_DrawLine(uint16_t x1, uint16_t y1, uint16_t x2, uint16_t y2,
                     uint16_t color);
void ST7789_DrawRectangle(uint16_t x1, uint16_t y1, uint16_t x2, uint16_t y2,
                          uint16_t color);
void ST7789_DrawCircle(uint16_t x0, uint16_t y0, uint8_t r, uint16_t color);
void ST7789_DrawImage(uint16_t x, uint16_t y, uint16_t w, uint16_t h,
                      const uint16_t *data);
void ST7789_InvertColors(uint8_t invert);
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

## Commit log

2026-06-22 add switches to schematic
    [mockup.blend, pipapda.kicad_pcb, pipapda.kicad_sch]
2026-06-23 add internal parts to mockup
    [mockup.blend, pipapda.kicad_sch]
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2026-06-24 migrate all parts to easyeda2kicad footprints
    [pipapda.kicad_sch]
2026-06-24 fix decal on mockup
    [mockup.blend]
2026-06-24 colorcode keys on keyboard and fix layout
    [mockup.blend]
2026-06-24 replace connector with proper one
    [pipapda.kicad_sch]
2026-06-25 add decouplers and switches for boot0 and nrst
    [mockup.blend, pipapda.kicad_sch]
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2026-06-25 add crystal oscillator
    [ittypda.kicad_sch, mockup.blend]
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2026-06-25 add BQ24040 charging IC
    [ittypda.kicad_sch]
2026-06-26 add linear regulator.. we have power!!!
    [ittypda.kicad_sch]
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2026-06-26 fix JST connector side
    [ittypda.kicad_sch]
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2026-06-26 replace all old switch symbols
    [ittypda.kicad_sch]
2026-06-26 add labels to FPC connector pins
    [ittypda.kicad_sch]
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2026-06-26 connect FPC pins to ic gpios
    [ittypda.kicad_sch]
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2026-06-26 add debug pins footprint
    [ittypda.kicad_sch]
2026-06-26 connect keyboard matrix pins to GPIO
    [ittypda.kicad_sch]
2026-06-26 add a power slide switch that cuts off 3v3 and also removed the NRST switch
    [ittypda.kicad_sch]
2026-06-26 fix slide switch
    [ittypda.kicad_sch]
2026-06-26 use bigger footprint for slide switch
    [ittypda.kicad_sch]
2026-06-26 add values and footprint for charging status LED
    [ittypda.kicad_sch]
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2026-06-28 layout keyboard in pcb (not accurate spacings, and no diodes)
    [ittypda.kicad_pcb]
2026-06-28 place all caps and resistors (not final positions)
    [ittypda.kicad_pcb]
2026-06-28 add 3d model for usb c port and finalize initial placement of parts (not diodes yet)
    [ittypda.kicad_pcb, ittypda.kicad_sch]
2026-06-29 snap all keys to grid
    [ittypda.kicad_pcb]
2026-06-29 placed all switch diodes!
    [ittypda.kicad_pcb]
2026-06-29 layout front side of board
    [ittypda.kicad_pcb]
2026-06-29 split power circuitry into seperate PCB part
    [ittypda.kicad_pcb, ittypda.kicad_sch]
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2026-06-29 move mousebites to bottom of pcb
    [ittypda.kicad_pcb]
2026-06-29 add gap for wires to connect through
    [ittypda.kicad_pcb]
2026-06-30 wire keyboard matrix switches
    [ittypda.kicad_pcb]
2026-06-30 connect rows of keyboard matrix to microcontroller
    [ittypda.kicad_pcb, ittypda.kicad_sch]
2026-06-30 wire columns to mc
    [ittypda.kicad_pcb]
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2026-06-30 change connector type between the two pcbs and wire it up on the mainboard
    [ittypda.kicad_pcb, ittypda.kicad_sch]
2026-06-30 align connectors between boards (secondary board is flipped)
    [ittypda.kicad_pcb]
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2026-07-01 move power lines away from usb data lines
    [ittypda.kicad_pcb]
2026-07-01 switch states of the power slide button
    [ittypda.kicad_pcb, ittypda.kicad_sch]
2026-07-01 add labels to JST connector for safety
    [ittypda.kicad_pcb]
2026-07-01 wired up debug headers
    [ittypda.kicad_pcb]
2026-07-01 adjust data lines length to match better
    [ittypda.kicad_pcb]
2026-07-02 start adding ground plane
    [ittypda.kicad_pcb]
2026-07-02 move USB-C port so it doesnt stick out
    [ittypda.kicad_pcb]
2026-07-02 change clearance of pads of BQ24040DSQR
    [ittypda.kicad_pcb]
2026-07-02 solve almost every design violation
    [ittypda.kicad_pcb, ittypda.kicad_sch]
2026-07-02 fix some footprint attributes
    [ittypda.kicad_pcb, ittypda.kicad_sch]
2026-07-02 add third mouse bite
    [ittypda.kicad_pcb, ittypda.kicad_sch]
2026-07-02 fix warning about a footprint
    [ittypda.kicad_pcb]
2026-07-03 change microcontroller to the STM32F411RET6
    [ittypda.kicad_pcb, ittypda.kicad_sch]
2026-07-03 correct value of VDDA cap
    [ittypda.kicad_sch]
2026-07-03 replace 0.1µF with 100nF for consistency
    [ittypda.kicad_sch]
2026-07-03 update pcb with new cap values
    [ittypda.kicad_pcb]
2026-07-03 move boot0 button and repair edge cuts
    [ittypda.kicad_pcb]
2026-07-04 add silkscreen art !!
    [ittypda.kicad_pcb]
2026-07-04 even out usb data lines
    [ittypda.kicad_pcb]
2026-07-04 label all header pins and move boot0 button slightly
    [ittypda.kicad_pcb]
2026-07-04 updated 'dont bend' art
    [ittypda.kicad_pcb]
2026-07-04 add board version to pcb silkscreen
    [ittypda.kicad_pcb]
2026-07-06 add extra power line to display
    [ittypda.kicad_pcb]
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2026-07-09 fix error from display lib
    [st7789.c]
2026-07-10 add test points for power
    [ittypda.kicad_pcb, ittypda.kicad_sch]
2026-07-10 unlock switch on pcb
    [ittypda.kicad_pcb]
2026-07-10 replace voltage regulator with buck-boost converter (schematic only)
    [ittypda.kicad_sch]
2026-07-10 update pcb with buck-boost
    [ittypda.kicad_pcb]
2026-07-10 add custom label for BCHG test pad
    [ittypda.kicad_pcb]
2026-07-10 remove some footprints labels
    [ittypda.kicad_pcb]
2026-07-10 correct (?) cap value for VCAP to 4.7
    [ittypda.kicad_sch]
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2026-07-12 add pull-down resistor to TS
    [ittypda.kicad_pcb, ittypda.kicad_sch]
2026-07-13 fix cropped image rendering edge cases
    [graphics.c, system.c]
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2026-07-13 fix bq24040 configuration again i think? im so confused by the different modes related to the TS pin but i think this is what i want? similar open sauce project seem to leave the pin floating or pull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
    [ittypda.kicad_pcb, ittypda.kicad_sch]
2026-07-13 change 0.1uF to 100nF
    [ittypda.kicad_sch]
2026-07-14 replace with cheaper resistors
    [ittypda.kicad_pcb, ittypda.kicad_sch]
2026-07-14 improve some wiring around display connector and usbc
    [ittypda.kicad_pcb]
2026-07-14 remove usb termination resistors, not needed for stm boards
    [ittypda.kicad_sch]
2026-07-14 update pcb with regards to usb termination resistors
    [ittypda.kicad_pcb]
2026-07-14 add decoupler for Vbat
    [ittypda.kicad_pcb, ittypda.kicad_sch]
2026-07-14 spread out signal lines for better signal integrity
    [ittypda.kicad_pcb]
2026-07-15 move sck pin and remove sharp turns in MISO and SCK traces
    [ittypda.kicad_pcb, ittypda.kicad_sch]
2026-07-15 reorder row pins to reduce sharp angles
    [ittypda.kicad_pcb, ittypda.kicad_sch]
2026-07-15 move decouplers to more optimal locations
    [ittypda.kicad_pcb, ittypda.kicad_sch]
2026-07-16 add PCBA mounting holes to schematic
    [ittypda.kicad_pcb, ittypda.kicad_sch]
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2026-07-27 repalce buck-boost with fixed output 3v3 linear regulator. its cheaper, and for battery health its probably good to not discharge it to under 3.3v, which is still only losing out on like 5% or so. fa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
    [ittypda.kicad_pcb, ittypda.kicad_sch]
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2026-07-27 fix problems with battery indicator
2026-07-29 replace voltage reading battery level analyzer with dedicated IC
    [ittypda.kicad_pcb, ittypda.kicad_sch]
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2026-08-01 work on case (in blender because freecad was hard)
    [ittypda.FCStd]
2026-08-01 fix spacings in case
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2026-08-01 add .blend for 3d printable version of case file
    [case-printable.blend]
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2026-08-03 fix misaligned case part
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2026-08-05 input box on home app and fix memset_u16 overflow bug
    [graphics.c, system.c]
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2026-08-06 fix text print in test.c
    [system.c]
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2026-08-07 add .step file (converted from stl with https://imagetostl.com/convert/file/stl/to/step)
    [case-printable.stl]
2026-08-07 fix bad formatted rows
    [parts-bom.csv]
